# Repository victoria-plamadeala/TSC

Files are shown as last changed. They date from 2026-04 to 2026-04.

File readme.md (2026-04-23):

# InkTime - Smartwatch Project

## Descriere Generala
Acest proiect vizeaza designul si integrarea unui smartwatch bazat pe nRF52840, utilizand un display e-paper de 1.54 inch pentru eficienta energetica. Dispozitivul include circuite de management al alimentarii pentru o baterie Li-Po de 250mAh si un motor haptic pentru notificari.

---

## 1. Diagrama Bloc
Diagrama de mai jos ilustreaza interactiunea dintre unitatea centrala (MCU nRF52840) si perifericele integrate (Display, Haptic Driver, Senzori, Management Alimentare).

Diagrama Bloc

---

## 2. PCB Design & Layout

### Placement si Routing
* **Placement:** Componentele au fost grupate logic pentru a minimiza lungimea traseelor si a reduce interferentele electromagnetice, avand in vedere densitatea ridicata pe o suprafata de doar 46 x 35 mm.
* **Routing:** Din cauza complexitatii si a numarului mare de componente pe o placa de dimensiuni reduse, s-a utilizat o combinatie de rutare manuala pentru liniile critice si autorouter-ul din Fusion Autodesk pentru restul conexiunilor.

PCB Layout Fata
PCB Layout Spate

### Detalii de Fabricatie si Asamblare
PCB-ul este optimizat pentru productie industriala, respectand urmatoarele reguli de design:
* **Trasee de alimentare:** 0.3 mm.
* **Trasee de date/semnal:** 0.15 mm.
* **Integrare Mecanica:** Ansamblul a fost verificat prin modelare 3D, asigurand potrivirea perfecta a bateriei LP502030 si a display-ului in carcasa dedicata InkTime.

Toate fisierele necesare (Gerber, BOM, CPL) sunt disponibile in folderul `/Manufacturing`.

---

## 3. Alocarea pinilor Microcontroller-ului

| Componenta | Semnal | Pin nRF52840 |
| :--- | :--- | :--- |
| **Interfata E-Paper** | SCK | P0.31 |
| | DIN | P0.29 |
| | CS | P0.30 |
| | D/C | P1.13 |
| | RST | P0.02 (AIN0) |
| | BUSY | P0.03 (AIN1) |
| **Haptic Driver** | HAPTIC_EN | P1.12 |
| | SCL | P0.27 |
| | SDA | P0.26 |
| **Butoane (UI)** | Button 1 | P0.11 |
| | Button 2 | P0.12 |
| | Button 3 | P0.24 |

---

## Structura Repository
* **/Hardware**: Fisierele sursa Fusion 360 (.fsch, .fbrd).
* **/Mechanical**: Modelul 3D al ansamblului (.step).
* **/Manufacturing**: Arhiva Gerber, Bill of Materials (BOM) si Pick and Place (CPL).

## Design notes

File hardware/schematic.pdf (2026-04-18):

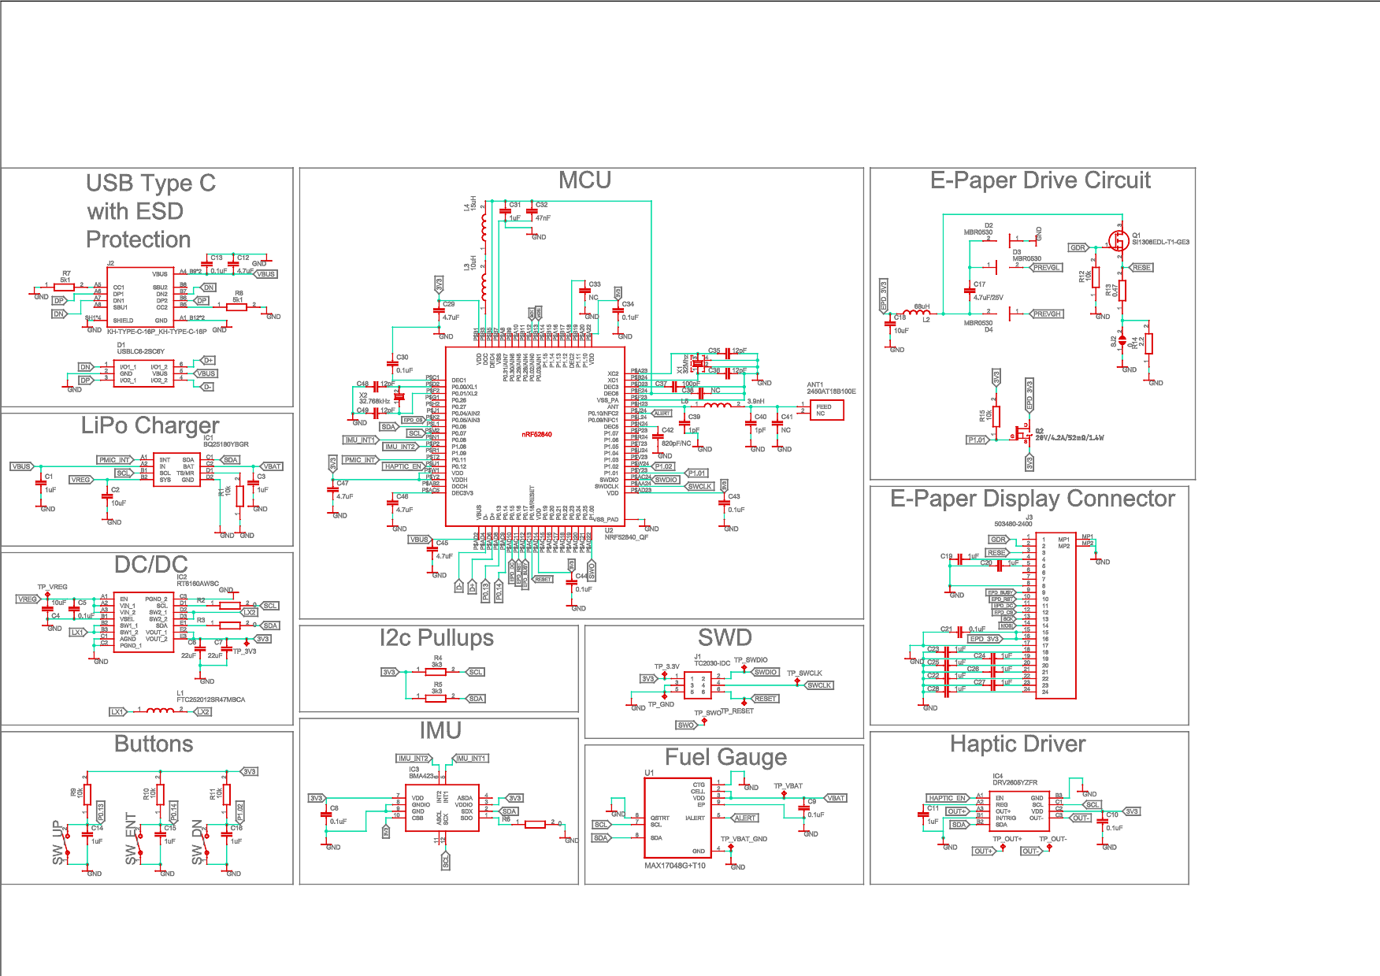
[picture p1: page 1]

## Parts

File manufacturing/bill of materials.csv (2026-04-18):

Qty | Value | Device | Package | Parts | Description | ARROW_PART_NUMBER | ARROW_PRICE-STOCK | AVAILABILITY | CHECK_PRICES | COPYRIGHT | DESCRIPTION | DIGI-KEY_PART_NUMBER_1 | DIGI-KEY_PART_NUMBER_2 | DIGI-KEY_PART_NUMBER_3 | HEIGHT | JLCPCB | MANUFACTURER_NAME | MANUFACTURER_PART_NUMBER | MF | MOUSER_PART_NUMBER | MOUSER_PRICE-STOCK | MP | PACKAGE | POPULARITY | PRICE | PROD_ID | PURCHASE-URL | SNAPEDA_LINK | TP_SIGNAL_NAME | VALUE
3 | 0 | CPF0201D7K68C1_CPF0201D7K68C1 | CPF0201D7K68C1_0201 | R2, R3, R6 | 7.68k 0201 Thin Film Surface Mount Fixed Resistor +/-0.5% 0.031W CPF0201D7K68C1
1 | 0 | ESP32_C6_LIBRARY_7_JUMPER_SJ | ESP32_C6_LIBRARY_7_JUMPER_SJ | SJ2 | SMD solder JUMPER |  |  |  |  |  |  |  |  |  |  |  |  |  |  |  |  |  |  | 3
10 | 0.1uF | NORDIC_NRF_3_CAPACITOR_0201_N | NORDIC_NRF_3_RESC0201_N | C5, C8, C9, C10, C13, C21, C30, C34, C43, C44 | Generic chip capacitor
1 | 0.47 | CPF0201D7K68C1_CPF0201D7K68C1 | CPF0201D7K68C1_0201 | R13 | 7.68k 0201 Thin Film Surface Mount Fixed Resistor +/-0.5% 0.031W CPF0201D7K68C1
1 | 100pF | NORDIC_NRF_3_CAPACITOR_0201_N | NORDIC_NRF_3_RESC0201_N | C37 | Generic chip capacitor
6 | 10k | CPF0201D7K68C1_CPF0201D7K68C1 | CPF0201D7K68C1_0201 | R1, R9, R10, R11, R12, R15 | 7.68k 0201 Thin Film Surface Mount Fixed Resistor +/-0.5% 0.031W CPF0201D7K68C1
3 | 10uF | NORDIC_NRF_3_CAPACITOR_0402_N | NORDIC_NRF_3_RESC0402_N | C2, C4, C18 | Generic chip capacitor
1 | 10uH | MLP2016SR47MT0S1_FTC252012SR47MBCA | MLP2016SR47MT0S1_INDC2016X100N | L3 | SMD / SMT Inductors (Coils), L=0.47?H, L x W x T : |  |  |  |  |  | SMD / SMT Inductors (Coils) | L=0.47?H | L x W x T : |  |  |  | 1mm | https://jlcpcb.com/partdetail/6763488-FTC252012SR47MBCA/C5832368 | TDK | FTC252012SR47MBCA
4 | 12pF | NORDIC_NRF_3_CAPACITOR_0201_N | NORDIC_NRF_3_RESC0201_N | C35, C36, C48, C49 | Generic chip capacitor
1 | 15uH | MLP2016SR47MT0S1_FTC252012SR47MBCA | MLP2016SR47MT0S1_INDC2016X100N | L4 | SMD / SMT Inductors (Coils), L=0.47?H, L x W x T : |  |  |  |  |  | SMD / SMT Inductors (Coils) | L=0.47?H | L x W x T : |  |  |  | 1mm | https://jlcpcb.com/partdetail/6763488-FTC252012SR47MBCA/C5832368 | TDK | FTC252012SR47MBCA
2 | 1pF | NORDIC_NRF_3_CAPACITOR_0201_N | NORDIC_NRF_3_RESC0201_N | C39, C40 | Generic chip capacitor
16 | 1uF | NORDIC_NRF_3_CAPACITOR_0402_N | NORDIC_NRF_3_RESC0402_N | C1, C3, C11, C14, C15, C16, C19, C20, C22, C23, C24, C25, C26, C27, C28, C31 | Generic chip capacitor
1 | 2.2 | CPF0201D7K68C1_CPF0201D7K68C1 | CPF0201D7K68C1_0201 | R14 | 7.68k 0201 Thin Film Surface Mount Fixed Resistor +/-0.5% 0.031W CPF0201D7K68C1
3 | 2025-10-22_07-23-44_LIBRARY_EVP-AKE31ASW_EVP-AKE31A_PAN | 2025-10-22_07-23-44_LIBRARY_EVP-AKE31ASW_EVP-AKE31A_PAN | 2025-10-22_07-23-44_LIBRARY_SW_EVP-AKE31A_PAN | SW_DN, SW_ENT, SW_UP |  |  |  |  |  | Copyright (C) 2025 Ultra Librarian. All rights reserved. |  | P123437TR-ND | P123437CT-ND | P123437DKR-ND |  |  | Panasonic | EVP-AKE31A
1 | 20V/4.2A/52mO/1.4W | ESP32_C6_LIBRARY_4_ESP32_WROVER_SPARKFUN-DISCRETESEMI_MOSFET_PCH-DMG2305UX-7 | ESP32_C6_LIBRARY_4_ESP32_C6_LIBRARY_4_ESP32_C6_LIBRARY_4_ESP32_C6_LIBRARY_4_ESP32_WROVER_SPARKFUN-DISCRETESEMI_SOT23-3 | Q2 | P-channel MOSFETs |  |  |  |  |  |  |  |  |  |  |  |  |  |  |  |  |  |  |  |  | TRAN-14388 |  |  |  | 20V/4.2A/52mO/1.4W
2 | 22uF | NORDIC_NRF_3_CAPACITOR_0402_N | NORDIC_NRF_3_RESC0402_N | C6, C7 | Generic chip capacitor
1 | 2450AT18B100E | 2450AT18B100E_2450AT18B100E | 2450AT18B100E_ANTC3216X140N | ANT1 | Antennas 2.45GHz ANTENNA | 2450AT18B100E | https://www.arrow.com/en/products/2450at18b100e/johanson-dielectrics?utm_currency=USD&region=nac |  |  |  | Antennas 2.45GHz ANTENNA |  |  |  | 1.4mm |  | JOHANSON TECHNOLOGY | 2450AT18B100E |  | 609-2450AT18B100E | https://www.mouser.co.uk/ProductDetail/Johanson-Technology/2450AT18B100E?qs=yCnrNFeXz%252Bh5MFsFIXGZGA%3D%3D
1 | 3.9nH | MLP2016SR47MT0S1_FTC252012SR47MBCA | MLP2016SR47MT0S1_INDC2016X100N | L5 | SMD / SMT Inductors (Coils), L=0.47?H, L x W x T : |  |  |  |  |  | SMD / SMT Inductors (Coils) | L=0.47?H | L x W x T : |  |  |  | 1mm | https://jlcpcb.com/partdetail/6763488-FTC252012SR47MBCA/C5832368 | TDK | FTC252012SR47MBCA
1 | 32.768kHz | NORDIC_NRF_1_XTAL_32KHZ | NORDIC_NRF_1_XTAL_3215_N | X2
1 | 32Mhz | NORDIC_NRF_XTAL_32MHZ | NORDIC_NRF_BT-XTAL_2016_N | X1
2 | 3k3 | CPF0201D7K68C1_CPF0201D7K68C1 | CPF0201D7K68C1_0201 | R4, R5 | 7.68k 0201 Thin Film Surface Mount Fixed Resistor +/-0.5% 0.031W CPF0201D7K68C1
5 | 4.7uF | NORDIC_NRF_3_CAPACITOR_0402_N | NORDIC_NRF_3_RESC0402_N | C12, C29, C45, C46, C47 | Generic chip capacitor
1 | 4.7uF/25V | NORDIC_NRF_3_CAPACITOR_0402_N | NORDIC_NRF_3_RESC0402_N | C17 | Generic chip capacitor
1 | 47nF | NORDIC_NRF_3_CAPACITOR_0201_N | NORDIC_NRF_3_RESC0201_N | C32 | Generic chip capacitor
1 | 503480-2400 | 503480-2400_503480-2400 | 503480-2400_5034802400 | J3 | FFC & FPC Connectors 0.5mm FPC RA SMT Dual Contact 24Ckt |  |  |  |  |  | FFC & FPC Connectors 0.5mm FPC RA SMT Dual Contact 24Ckt |  |  |  | 1.87mm |  | Molex | 503480-2400 |  | 538-503480-2400 | https://www.mouser.co.uk/ProductDetail/Molex/503480-2400?qs=OAhjpuo3Vu7efIoxFh9AOw%3D%3D
2 | 5k1 | CPF0201D7K68C1_CPF0201D7K68C1 | CPF0201D7K68C1_0201 | R7, R8 | 7.68k 0201 Thin Film Surface Mount Fixed Resistor +/-0.5% 0.031W CPF0201D7K68C1
1 | 68uH | NORDIC_NRF_2_INDUCTOR_0402_L | NORDIC_NRF_2_RESC0402_L | L2 | Generic chip inductor
1 | 820pF/NC | NORDIC_NRF_3_CAPACITOR_0201_N | NORDIC_NRF_3_RESC0201_N | C42 | Generic chip capacitor
1 | BMA423 | BMA423_BMA423 | BMA423_BMA423 | IC3 | Accelerometers Triaxial low-g 12bit Acceleration Sensor | BMA423 | https://www.arrow.com/en/products/bma423/bosch |  |  |  | Accelerometers Triaxial low-g 12bit Acceleration Sensor |  |  |  | 1mm |  | BOSCH | BMA423 |  | 262-BMA423 | https://www.mouser.co.uk/ProductDetail/Bosch-Sensortec/BMA423?qs=HXFqYaX1Q2xC%252BSgeGoX3mg%3D%3D
1 | BQ25180YBGR | BQ25180YBGR_BQ25180YBGR | BQ25180YBGR_BGA8C40P2X4_100X155X50 | IC1 | Charger IC Lithium Ion/Polymer, Lithium Iron Phosphate 8-DSBGA (1.6x1.1) | BQ25180YBGR | https://www.arrow.com/en/products/bq25180ybgr/texas-instruments?utm_currency=USD&region=nac |  |  |  | Charger IC Lithium Ion/Polymer | Lithium Iron Phosphate 8-DSBGA (1.6x1.1) |  |  |  | 0.5mm |  | Texas Instruments | BQ25180YBGR |  | 595-BQ25180YBGR | https://www.mouser.co.uk/ProductDetail/Texas-Instruments/BQ25180YBGR?qs=doiCPypUmgEWjAK%252BJAX6Tw%3D%3D
1 | DRV2605YZFR | DRV2605YZFR_DRV2605YZFR | DRV2605YZFR_BGA9C50P3X3_144X144X62 | IC4 | Haptic Driver for ERM/LRA with Built-In Library and Smart Loop Architecture | DRV2605YZFR | https://www.arrow.com/en/products/drv2605yzfr/texas-instruments?region=nac |  |  |  | Haptic Driver for ERM/LRA with Built-In Library and Smart Loop Architecture |  |  |  | 0.625mm |  | Texas Instruments | DRV2605YZFR
1 | FTC252012SR47MBCA | MLP2016SR47MT0S1_FTC252012SR47MBCA | MLP2016SR47MT0S1_INDC2016X100N | L1 | SMD / SMT Inductors (Coils), L=0.47?H, L x W x T : |  |  |  |  |  | SMD / SMT Inductors (Coils) | L=0.47?H | L x W x T : |  |  |  | 1mm | https://jlcpcb.com/partdetail/6763488-FTC252012SR47MBCA/C5832368 | TDK | FTC252012SR47MBCA
12 | HECTOR_WATCH_1_TPTP20R | HECTOR_WATCH_1_TPTP20R | HECTOR_WATCH_1_TP20R | TP_3.3V, TP_3V3, TP_GND, TP_OUT+, TP_OUT-, TP_RESET, TP_SWCLK, TP_SWDIO, TP_SWO, TP_VBAT, TP_VBAT_GND, TP_VREG | Test pad |  |  |  |  |  |  |  |  |  |  |  |  |  |  |  |  |  |  | 2
1 | KH-TYPE-C-16P_KH-TYPE-C-16P | KH-TYPE-C-16P_KH-TYPE-C-16P | KH-TYPE-C-16P_KINGHELM_KH-TYPE-C-16P | J2 | Check availability |  |  | Not in stock | https://www.snapeda.com/parts/KH-TYPE-C-16P/Kinghelm/view-part/?ref=eda |  |  |  |  |  |  |  |  |  | kinghelm |  |  | KH-TYPE-C-16P | None |  | None |  |  | https://www.snapeda.com/parts/KH-TYPE-C-16P/Kinghelm/view-part/?ref=snap
1 | MAX17048G+T10 | ESP32_C6_LIBRARY_MAX17048G+T10 | ESP32_C6_LIBRARY_SON50P200X200X80-9N | U1 | Check availability |  |  | In Stock | https://www.snapeda.com/parts/MAX17048G+T10/Analog+Devices/view-part/?ref=eda |  | 3µA 1-Cell/2-Cell Fuel Gauge with ModelGauge |  |  |  |  |  |  |  | Analog Devices |  |  | MAX17048G+T10 | TDFN-8 Maxim |  | None |  | https://www.snapeda.com/api/url_track_click_mouser/?unipart_id=329239&manufacturer=Analog Devices&part_name=MAX17048G+T10&search_term=None | https://www.snapeda.com/parts/MAX17048G+T10/Analog+Devices/view-part/?ref=snap
3 | MBR0530 | ESP32_C6_LIBRARY_5_MBR0530 | ESP32_C6_LIBRARY_5_SOD3716X135N | D2, D3, D4 | ON SEMICONDUCTOR - MBR0530 - DIODE, SCHOTTKY, 0.5A, 30V, SOD-123 |  |  | In Stock | https://www.snapeda.com/parts/MBR0530/Onsemi/view-part/?ref=eda |  | Diode Schottky 30 V 500mA Surface Mount SOD-123 |  |  |  |  |  |  |  | ON Semiconductor |  |  | MBR0530 | SOD-123-2 ON Semiconductor |  | None |  | https://www.snapeda.com/api/url_track_click_mouser/?unipart_id=179458&manufacturer=ON Semiconductor&part_name=MBR0530&search_term=None | https://www.snapeda.com/parts/MBR0530/Onsemi/view-part/?ref=snap
3 | NC | NORDIC_NRF_3_CAPACITOR_0201_N | NORDIC_NRF_3_RESC0201_N | C33, C38, C41 | Generic chip capacitor
1 | NRF52840_QF | NORDIC_NRF_4_NRF52840_QF | NORDIC_NRF_4_AQFN50P700X700X85_HS-74N | U2 | nRF52840
1 | RT6160AWSC | RT6160AWSC_RT6160AWSC | RT6160AWSC_BGA15C40P3X5_140X230X60 | IC2 | Buck-Boost Regulator Positive Output Step-Up/Step-Down I2C DC-DC Controller IC 15-WL-CSP (BSC) (1.4x2.3) |  |  |  |  |  | Buck-Boost Regulator Positive Output Step-Up/Step-Down I2C DC-DC Controller IC 15-WL-CSP (BSC) (1.4x2.3) |  |  |  | 0.6mm |  | RICHTEK | RT6160AWSC |  | 835-RT6160AWSC | https://www.mouser.co.uk/ProductDetail/Richtek/RT6160AWSC?qs=amGC7iS6iy%2FLd9PSoixZXQ%3D%3D
1 | SI1308EDL-T1-GE3 | ESP32_C6_LIBRARY_6_SI1308EDL-T1-GE3 | ESP32_C6_LIBRARY_6_SOT65P210X110-3N | Q1 | MOSFET N-Ch 30V 1.5A TrenchFET SC70 Vishay Si1308EDL-T1-GE3 N-channel MOSFET Transistor, 1.5 A, 30 V, 3-Pin SC-70 |  |  | In Stock | https://www.snapeda.com/parts/SI1308EDL-T1-GE3/Vishay+Siliconix/view-part/?ref=eda |  | Si1308EDL-T1-GE3 N-channel MOSFET Transistor | 1.5 A | 30 V | 3-Pin SC-70 | Siliconix / Vishay SI1308EDL-T1-GE3 |  |  |  |  |  |  |  | Vishay Siliconix |  |  | SI1308EDL-T1-GE3 | SOT-323 Vishay Semiconductor |  | None |  | https://www.snapeda.com/api/url_track_click_mouser/?unipart_id=274603&manufacturer=Vishay Siliconix&part_name=SI1308EDL-T1-GE3&search_term=None
1 | TC2030-IDC | TC2030-IDC_TC2030-IDC | TC2030-IDC_TC2030IDC | J1 | CABLE ADAPTER 6 POS |  |  |  |  |  | CABLE ADAPTER 6 POS |  |  |  | 19mm |  | Tag Connect | TC2030-IDC
1 | USBLC6-2SC6Y | ESP32_C6_LIBRARY_3_USBLC6-2SC6Y | ESP32_C6_LIBRARY_3_SOT95P280X145-6N | D1 | Low Cap. ESD Protection Auto SOT-23-6 STMicroelectronics USBLC6-2SC6Y, Dual Uni-Directional TVS Diode Array, 6-Pin SOT-23 |  |  | In Stock | https://www.snapeda.com/parts/USBLC6-2SC6Y/STMicroelectronics/view-part/?ref=eda |  | 17V Clamp 5A (8/20µs) Ipp Tvs Diode Surface Mount SOT-23-6 |  |  |  |  |  |  |  | STMicroelectronics |  |  | USBLC6-2SC6Y | SOT-23-6 STMicroelectronics |  | None |  |  | https://www.snapeda.com/parts/USBLC6-2SC6Y/STMicroelectronics/view-part/?ref=snap

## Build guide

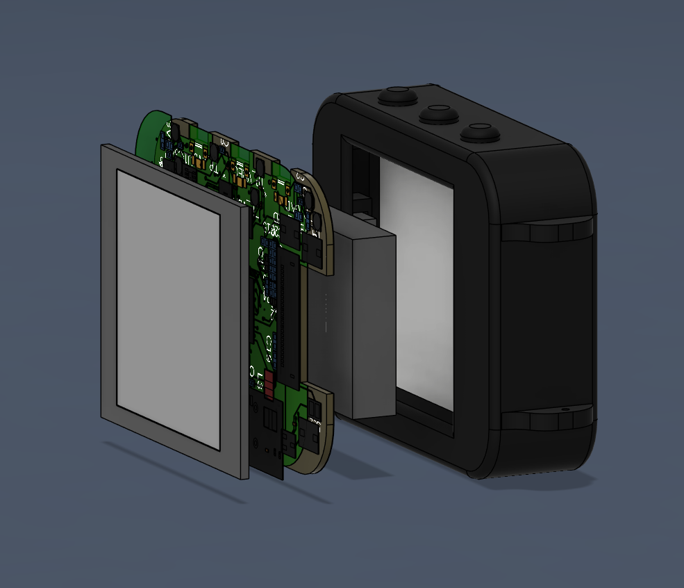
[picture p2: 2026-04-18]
mechanical/smartwatch assemblied.png

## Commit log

2026-04-18 project done (kinda)
    [bill of materials.csv, pick and place.csv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]
2026-04-23 enhanced readme
    Updated the readme to include detailed sections on PCB design, layout, and pin allocation for the microcontroller. Added images and improved formatting for better clarity.
